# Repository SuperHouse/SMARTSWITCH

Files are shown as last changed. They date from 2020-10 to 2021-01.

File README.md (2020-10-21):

SuperHouse Home Automation SmartSwitch
=======================================

Home automation light switch that can be constructed with different
button panels, all using the same logic board. This allows the same
logic board and software to be used for either single-colour or RGB
button panels, in sizes from 1 to 4 buttons.

The switch can either operate in isolation using WiFi and local power,
or it can connect to a central light switch controller via Cat-5
cable.

It's designed to mount in a standard Australian blank wall plate,
but can also fit other types of wall plate.

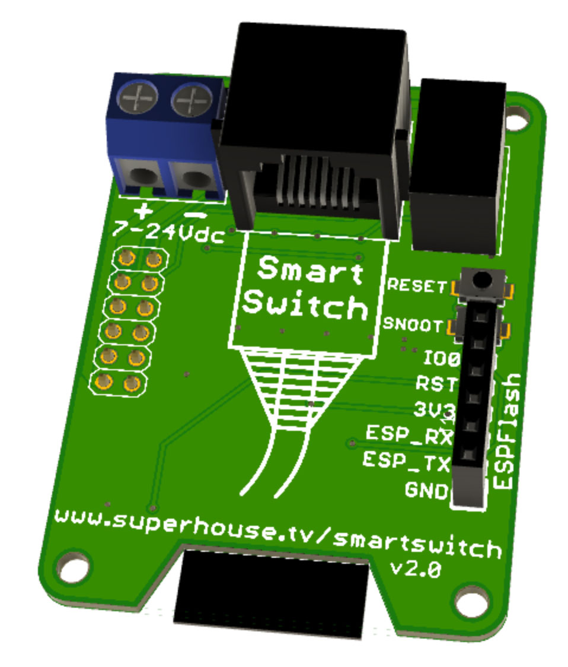
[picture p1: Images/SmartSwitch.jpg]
SmartSwitch


Features:

 * ESP8266 with WiFi
 * RJ45 socket to allow connecting using Cat-5 cable.
 * Either single-colour or RGB buttons.
 * From 1 to 4 buttons per panel.
 * WS2811 LED controllers.

More information is available at:

  https://www.superhouse.tv/smartswitch

Hardware
--------
The "Hardware" directory contains the PCB design as an EAGLE project.
EAGLE PCB design software is available from Autodesk free for
non-commercial use.

Credits
-------
 * Jonathan Oxer <jon@oxer.com.au>

License
-------
Copyright 2014-2020 SuperHouse Automation Pty Ltd  www.superhouse.tv  

The hardware portion of this project is licensed under the TAPR Open
Hardware License (www.tapr.org/OHL). The "license" folder within this
repository contains a copy of this license in plain text format.

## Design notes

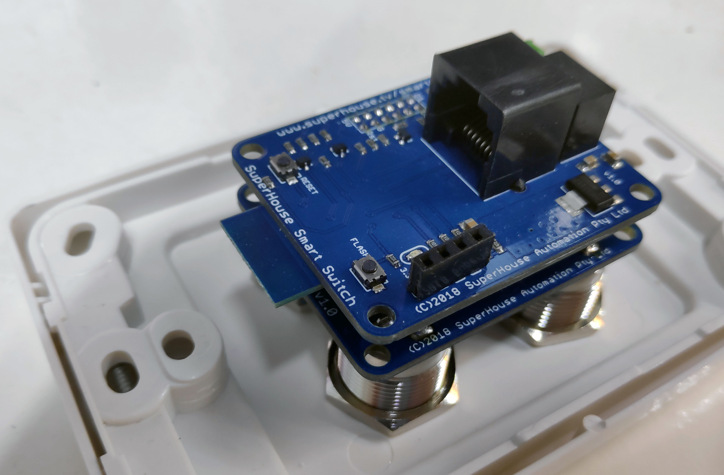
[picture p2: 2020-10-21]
Images/2019-02-13 13.19.25.jpg

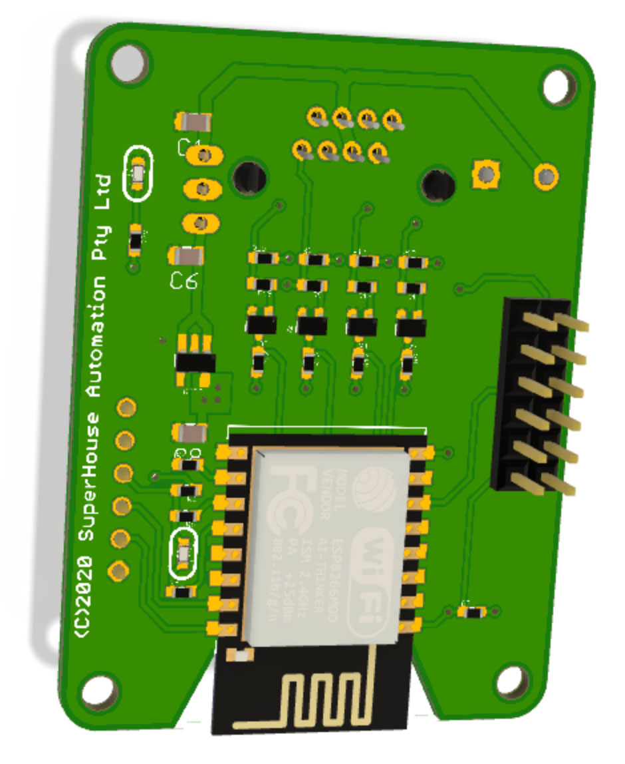
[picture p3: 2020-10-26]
Images/Screen Shot 2020-10-27 at 12.18.09 am.jpg

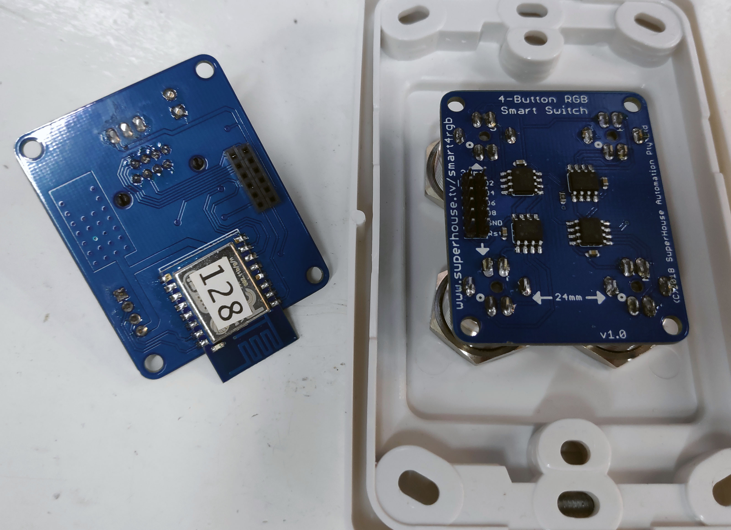
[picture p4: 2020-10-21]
Images/2019-02-13 13.19.00.jpg

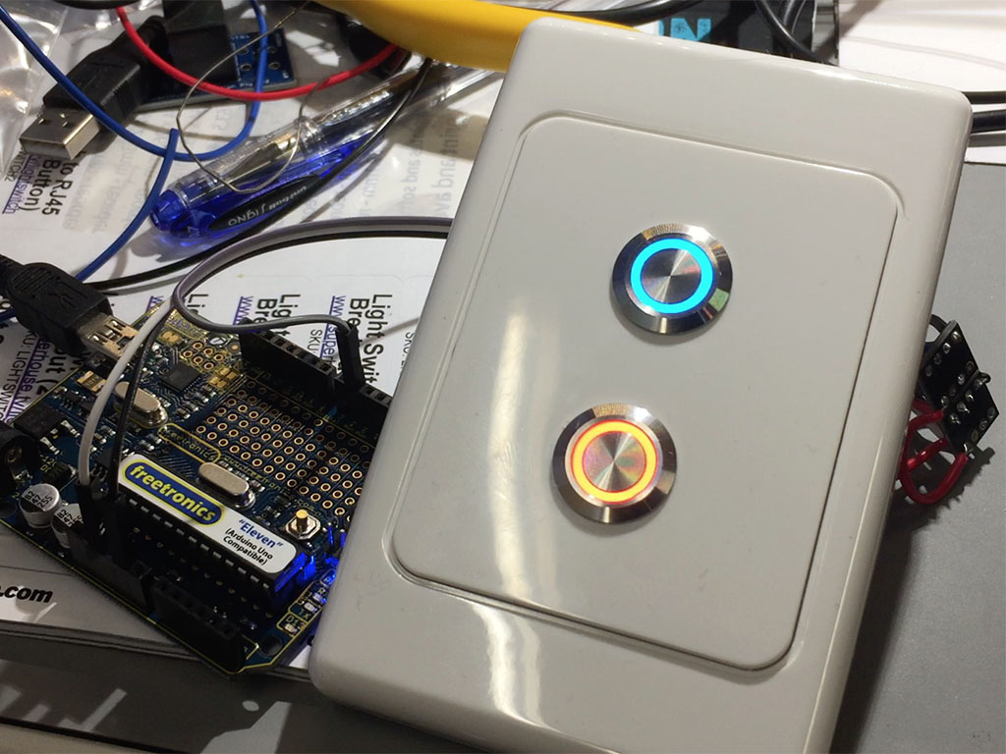
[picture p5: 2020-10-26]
Images/light-switch-prototype.jpg

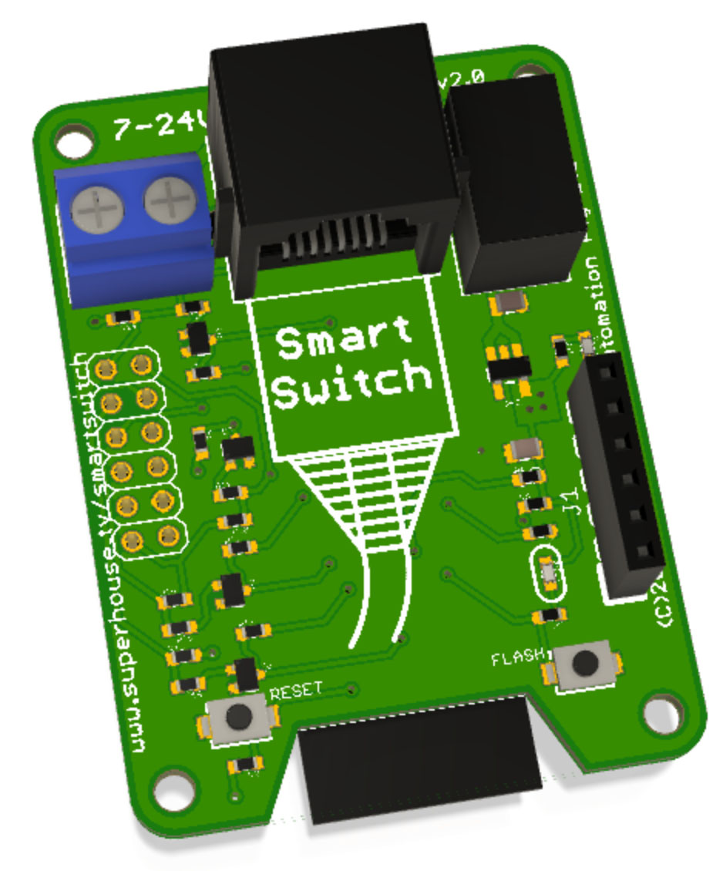
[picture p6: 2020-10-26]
Images/Screen Shot 2020-10-23 at 11.40.12 pm.jpg

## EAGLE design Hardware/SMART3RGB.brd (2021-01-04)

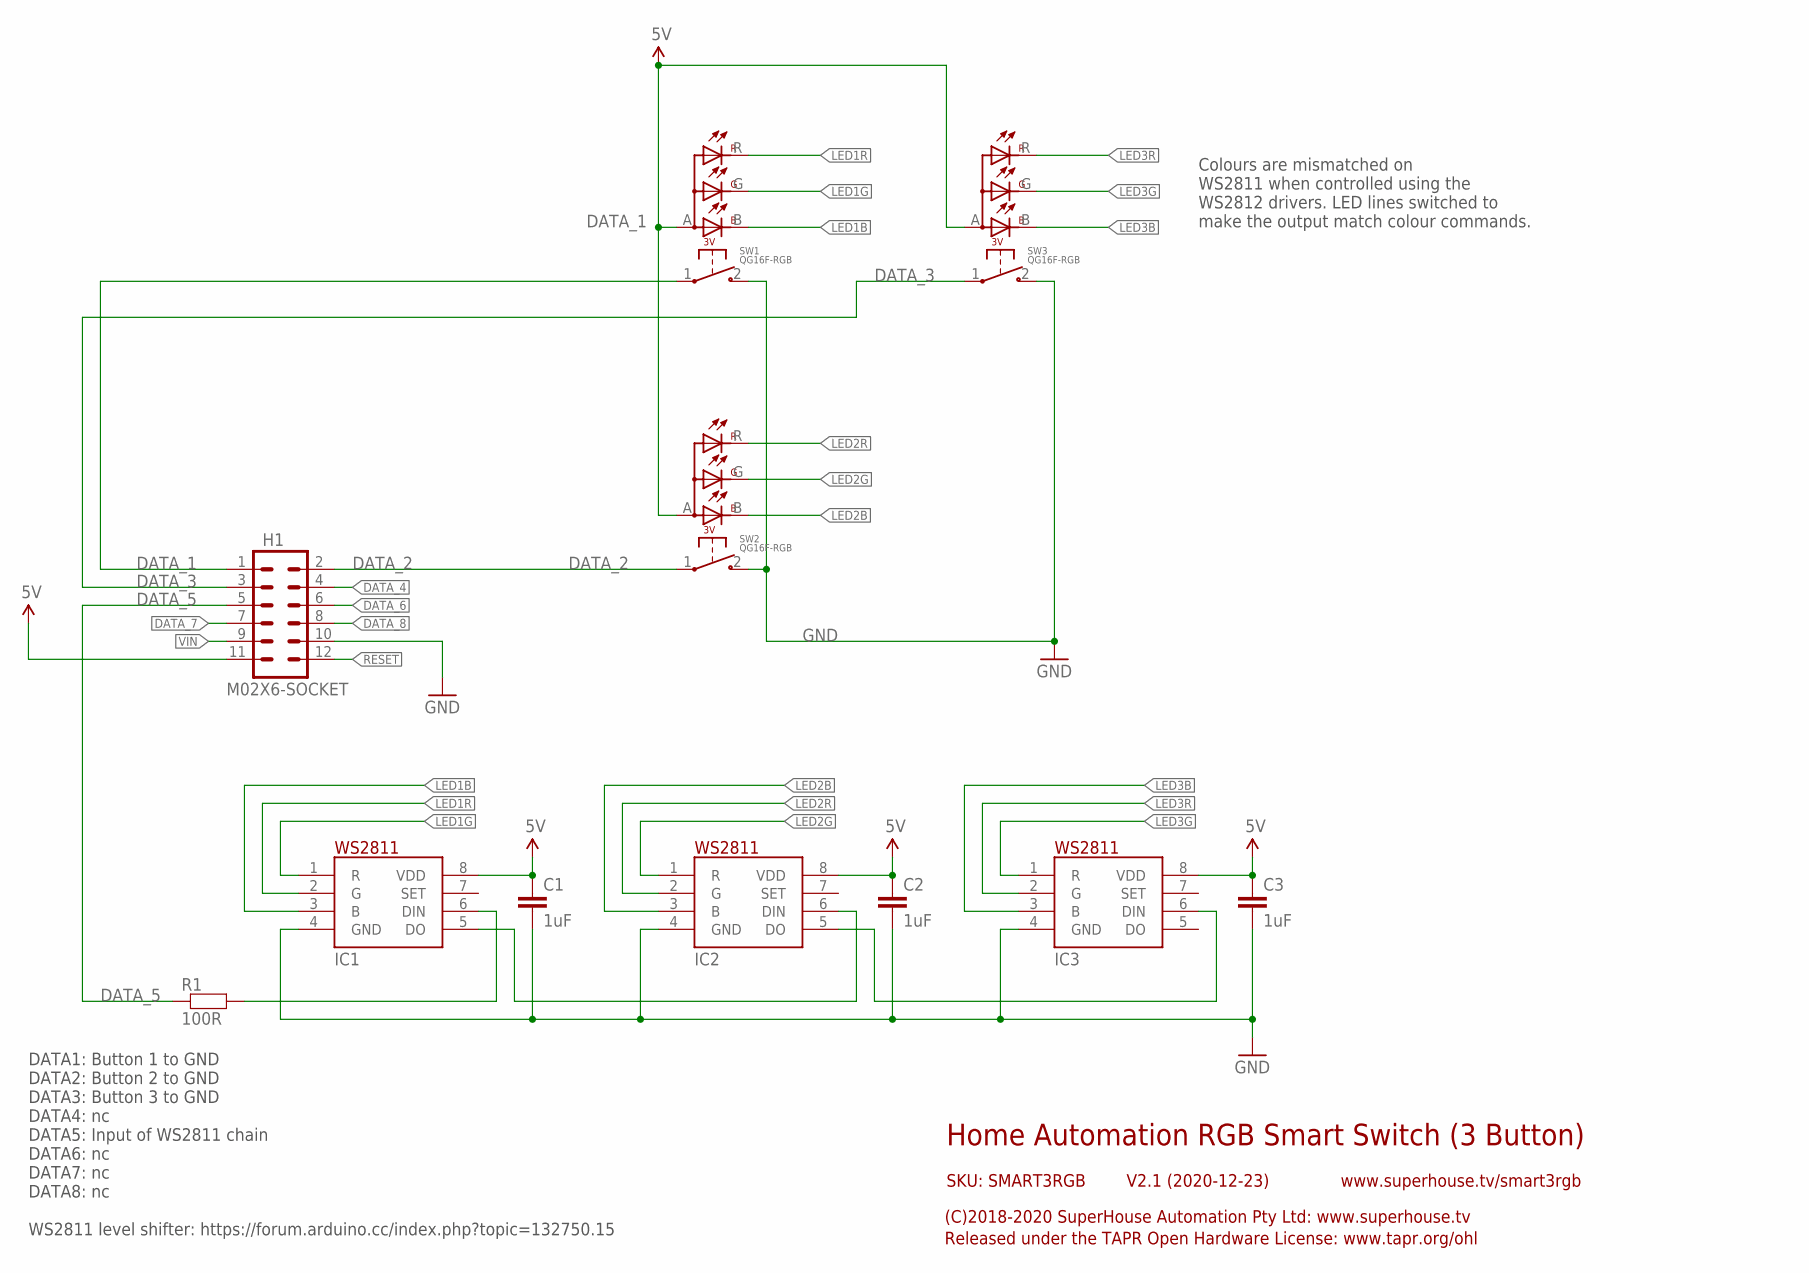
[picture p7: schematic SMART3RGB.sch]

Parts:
C1, C2, C3: 1uF; C0603
H1: M02X6-SOCKET; 2X06-S
IC1, IC2, IC3: WS2811-SOP8; SO08-SKINNYPADS
R1: 100R; R0603
SW1, SW2, SW3: QG16F-RGB

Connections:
5V: C1.1, C2.1, C3.1, H1.11, IC1.8 (VDD), IC2.8 (VDD), IC3.8 (VDD), SW1.A (+), SW2.A (+), SW3.A (+)
DATA_1: H1.1, SW1.1
DATA_2: H1.2, SW2.1
DATA_3: H1.3, SW3.1
DATA_4: H1.4
DATA_5: H1.5, R1.1
DATA_6: H1.6
DATA_7: H1.7
DATA_8: H1.8
GND: C1.2, C2.2, C3.2, H1.10, IC1.4 (GND), IC2.4 (GND), IC3.4 (GND), SW1.2, SW2.2, SW3.2
LED1B: IC1.3 (B), SW1.B
LED1G: IC1.1 (R), SW1.G
LED1R: IC1.2 (G), SW1.R
LED2B: IC2.3 (B), SW2.B
LED2G: IC2.1 (R), SW2.G
LED2R: IC2.2 (G), SW2.R
LED3B: IC3.3 (B), SW3.B
LED3G: IC3.1 (R), SW3.G
LED3R: IC3.2 (G), SW3.R
unnamed: IC1.6 (DIN), R1.2
unnamed: IC1.5 (DO), IC2.6 (DIN)
unnamed: IC2.5 (DO), IC3.6 (DIN)
RESET: H1.12
VIN: H1.9

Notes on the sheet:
Home Automation RGB Smart Switch (3 Button)
V2.1 (2020-12-23)
SKU: SMART3RGB
(C)2018-2020 SuperHouse Automation Pty Ltd: www.superhouse.tv
Released under the TAPR Open Hardware License: www.tapr.org/ohl
www.superhouse.tv/smart3rgb
DATA1: Button 1 to GND DATA2: Button 2 to GND DATA3: Button 3 to GND DATA4: nc DATA5: Input of WS2811 chain DATA6: nc DATA7: nc DATA8: nc WS2811 level shifter: https://forum.arduino.cc/index.php?topic=132750.15
Colours are mismatched on WS2811 when controlled using the WS2812 drivers. LED lines switched to make the output match colour commands.

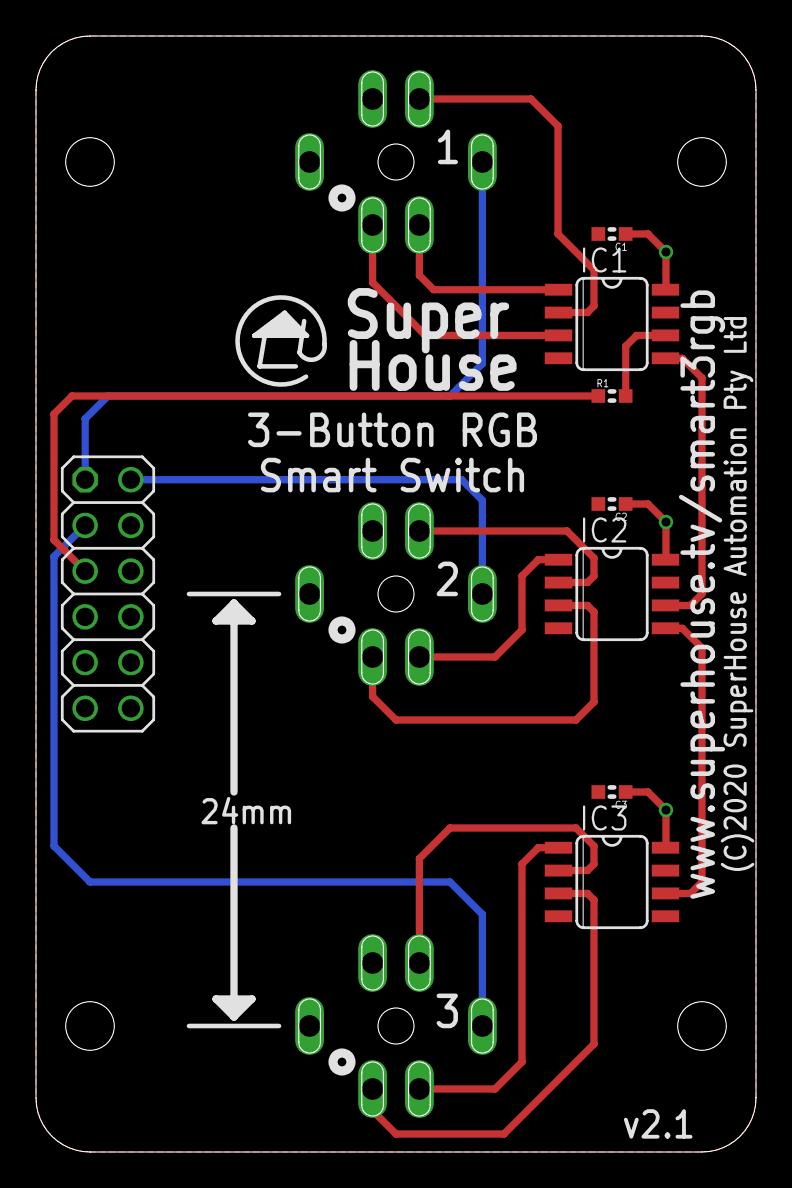
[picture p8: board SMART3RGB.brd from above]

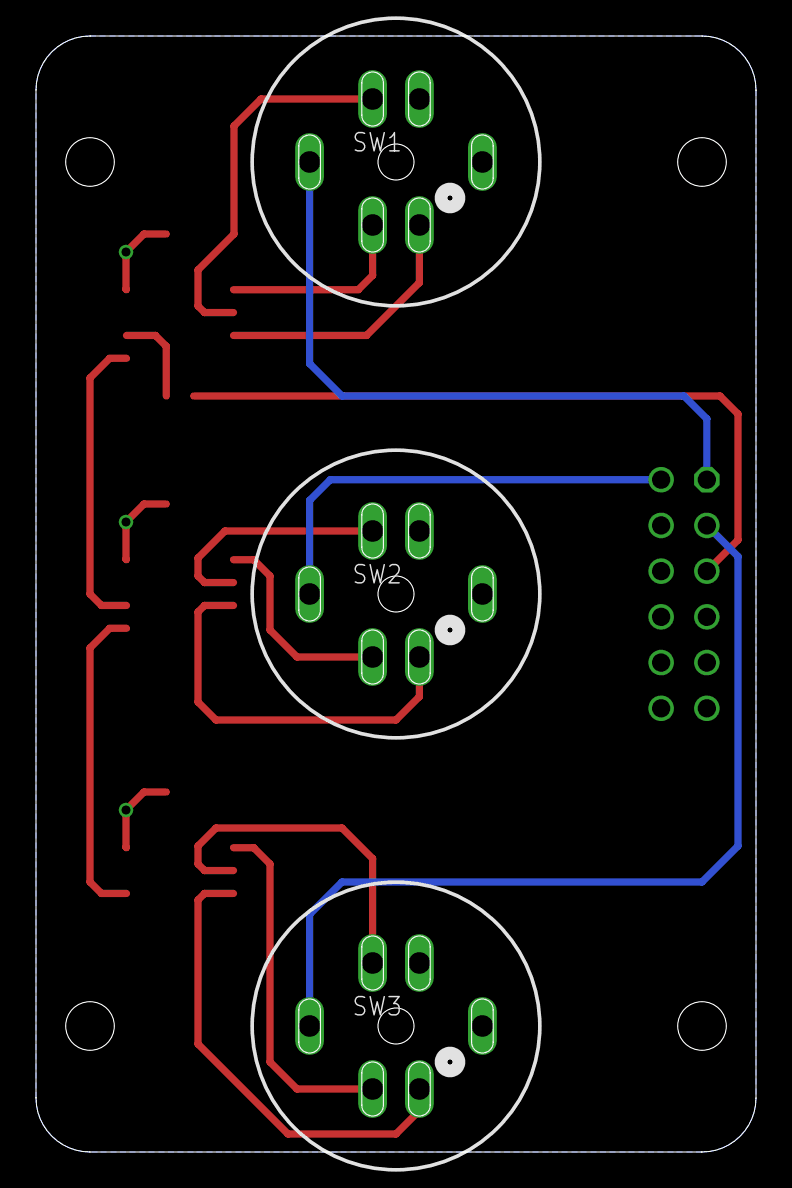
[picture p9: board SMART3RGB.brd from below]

Board: 2 copper layers, 40.0 x 62.0 mm, 11 parts (3 on the bottom side), 18 nets.

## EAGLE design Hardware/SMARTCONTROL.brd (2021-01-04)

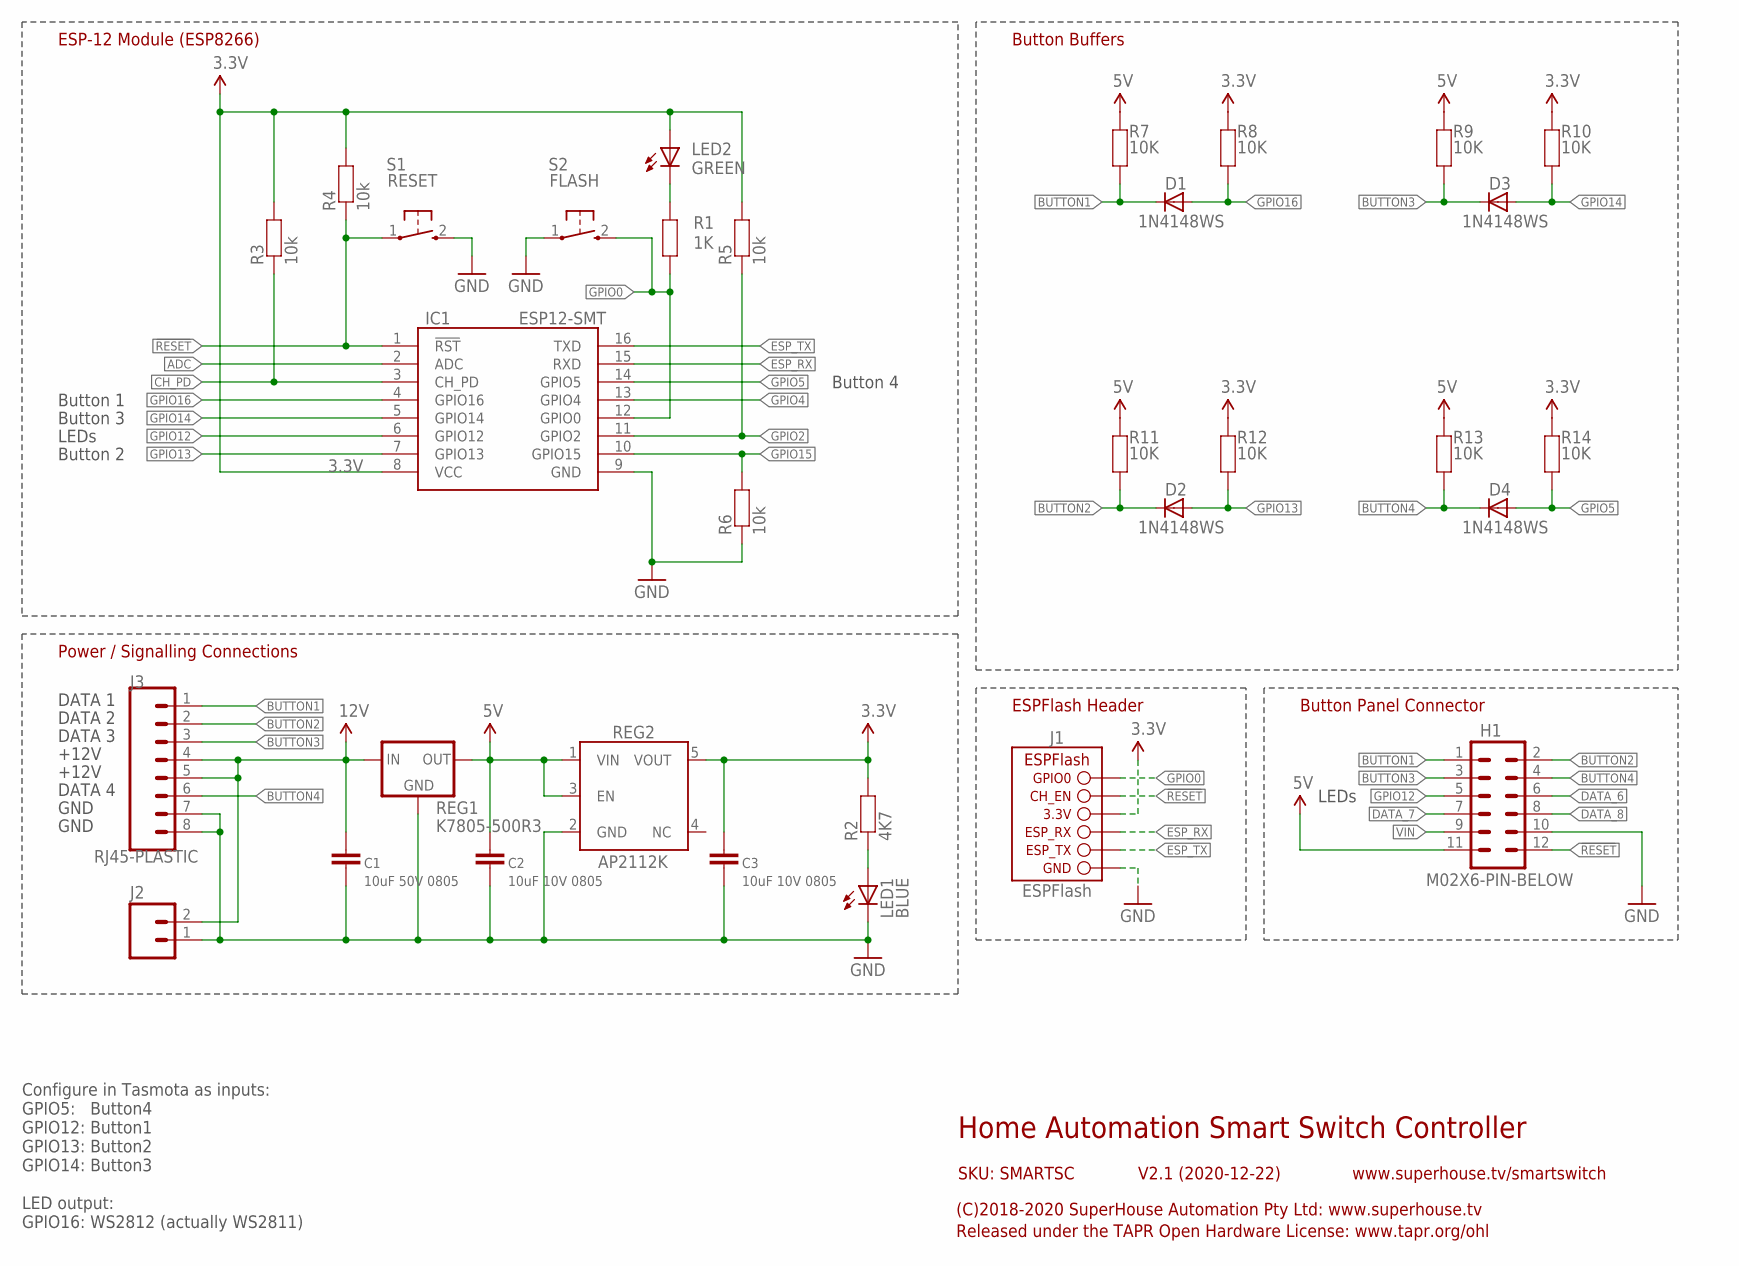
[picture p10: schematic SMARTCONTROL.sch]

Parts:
C1: 10uF 50V 0805; C0805
C2, C3: 10uF 10V 0805; C0805
D1, D2, D3, D4: 1N4148WS; SOD-323
H1: M02X6-PIN-BELOW; 2X06-P-BELOW
IC1: ESP12-SMT; ESP12
J1: ESPFLASH-1X6-2.54-SOCKET; 1X6-2.54-SOCKET
J2: M02-SCREW-5MM; SCREWTERMINAL-5MM-2
J3: RJ45-PLASTIC; RJ45
LED1: BLUE; LED-0603
LED2: GREEN; LED-0603
R1: 1K; R0603
R2: 4K7; R0603
R3, R4, R5, R6: 10k; R0603
R7, R8, R9, R10, R11, R12, R13, R14: 10K; R0603
REG1: K7805-500R3; K78XX-500R3
REG2: AP2112KSOT25; SOT23-5
S1: RESET; TACTILE_SMT_3X4X2
S2: FLASH; TACTILE_SMT_3X4X2

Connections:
3.3V: C3.1, IC1.8 (VCC), J1.4 (3.3V), LED2.A, R2.2, R3.2, R4.2, R5.2, R8.2, R10.2, R12.2, R14.2, REG2.5 (VOUT)
5V: C2.1, H1.11, R7.2, R9.2, R11.2, R13.2, REG1.3 (OUT), REG2.1 (VIN), REG2.3 (EN)
12V: C1.1, J2.2, J3.4, J3.5, REG1.1 (IN)
!RESET: H1.12, IC1.1 (!RST), J1.5 (CH_EN), R4.1, S1.1
ADC: IC1.2 (ADC)
BUTTON1: D1.1 (C), H1.1, J3.1, R7.1
BUTTON2: D2.1 (C), H1.2, J3.2, R11.1
BUTTON3: D3.1 (C), H1.3, J3.3, R9.1
BUTTON4: D4.1 (C), H1.4, J3.6, R13.1
CH_PD: IC1.3 (CH_PD), R3.1
DATA_6: H1.6
DATA_7: H1.7
DATA_8: H1.8
ESP_RX: IC1.15 (RXD), J1.3 (ESP_RX)
ESP_TX: IC1.16 (TXD), J1.2 (ESP_TX)
GND: C1.2, C2.2, C3.2, H1.10, IC1.9 (GND), J1.1 (GND), J2.1, J3.7, J3.8, LED1.C, R6.1, REG1.2 (GND), REG2.2 (GND), S1.2 (S), S2.1
GPIO0: IC1.12 (GPIO0), J1.6 (GPIO0), R1.2, S2.2 (S)
GPIO2: IC1.11 (GPIO2), R5.1
GPIO4: IC1.13 (GPIO4)
GPIO5: D4.2 (A), IC1.14 (GPIO5), R14.1
GPIO12: H1.5, IC1.6 (GPIO12)
GPIO13: D2.2 (A), IC1.7 (GPIO13), R12.1
GPIO14: D3.2 (A), IC1.5 (GPIO14), R10.1
GPIO15: IC1.10 (GPIO15), R6.2
GPIO16: D1.2 (A), IC1.4 (GPIO16), R8.1
unnamed: LED1.A, R2.1
unnamed: LED2.C, R1.1
VIN: H1.9

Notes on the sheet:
Home Automation Smart Switch Controller
V2.1 (2020-12-22)
SKU: SMARTSC
(C)2018-2020 SuperHouse Automation Pty Ltd: www.superhouse.tv
Released under the TAPR Open Hardware License: www.tapr.org/ohl
www.superhouse.tv/smartswitch
Configure in Tasmota as inputs: GPIO5: Button4 GPIO12: Button1 GPIO13: Button2 GPIO14: Button3 LED output: GPIO16: WS2812 (actually WS2811)
DATA 1
DATA 2
DATA 3
DATA 4
+12V
GND
Button 1
Button 2
Button 3
Button 4
LEDs
Button Panel Connector
ESP-12 Module (ESP8266)
Button Buffers
Power / Signalling Connections
ESPFlash Header

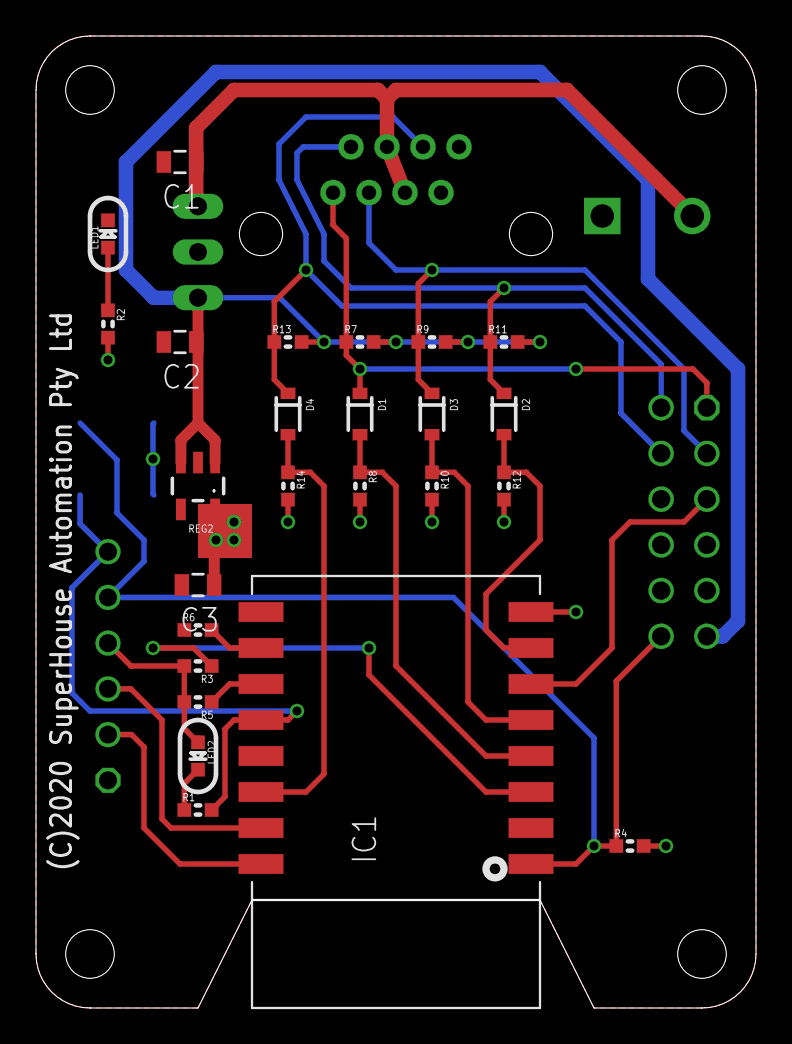
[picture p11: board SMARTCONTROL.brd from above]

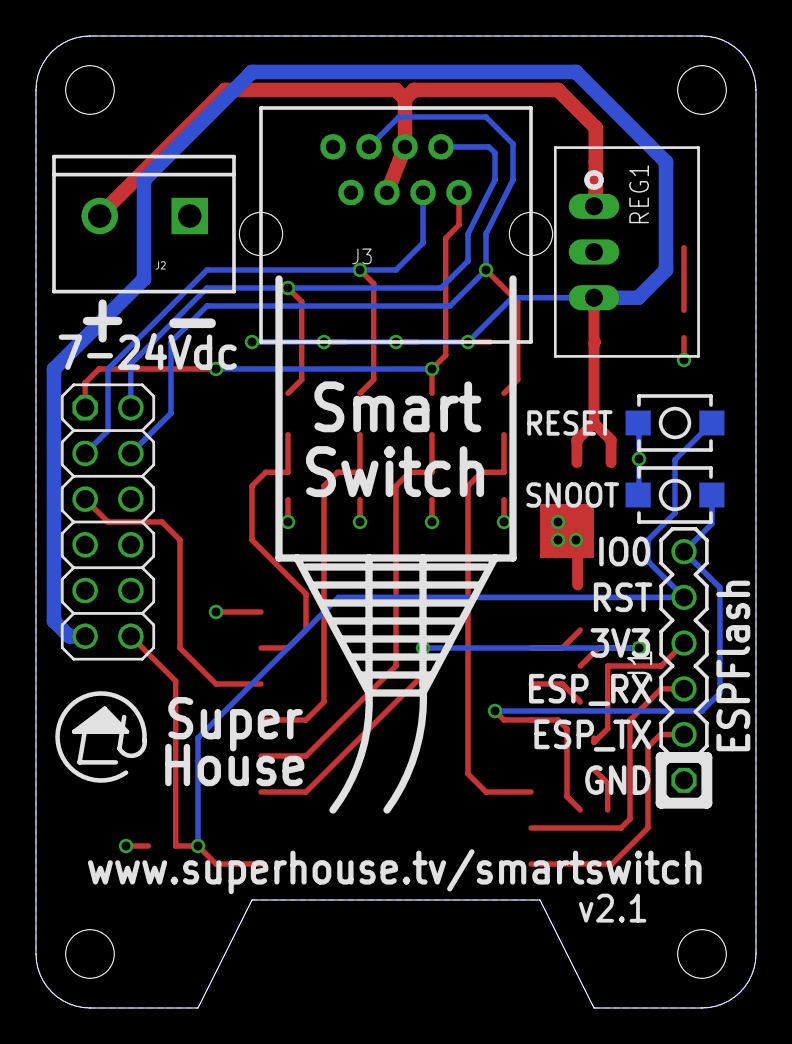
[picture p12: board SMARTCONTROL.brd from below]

Board: 2 copper layers, 40.0 x 54.0 mm, 32 parts (7 on the bottom side), 22 nets.

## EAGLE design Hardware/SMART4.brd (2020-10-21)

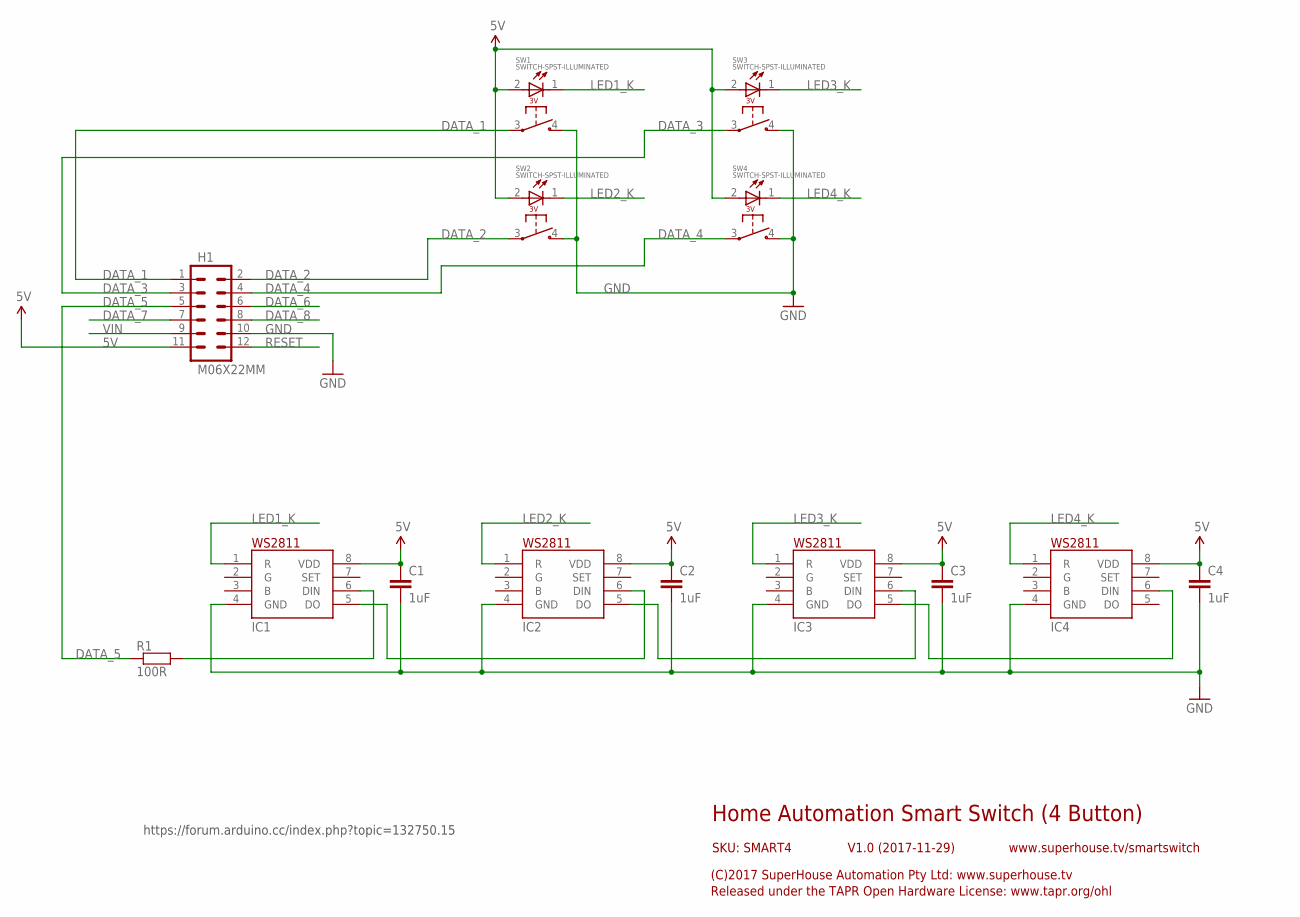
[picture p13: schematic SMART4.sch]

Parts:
C1, C2, C3, C4: 1uF; 0603
H1: M06X22MM; 2X6-2MM
IC1, IC2, IC3, IC4: WS2811-SOP8; SO08-SKINNYPADS
R1: 100R; 0603
SW1, SW2, SW3, SW4: SWITCH-SPST-ILLUMINATED

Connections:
5V: C1.1, C2.1, C3.1, C4.1, H1.11, IC1.8 (VDD), IC2.8 (VDD), IC3.8 (VDD), IC4.8 (VDD), SW1.2 (+), SW2.2 (+), SW3.2 (+), SW4.2 (+)
DATA_1: H1.1, SW1.3 (COM)
DATA_2: H1.2, SW2.3 (COM)
DATA_3: H1.3, SW3.3 (COM)
DATA_4: H1.4, SW4.3 (COM)
DATA_5: H1.5, R1.1
DATA_6: H1.6
DATA_7: H1.7
DATA_8: H1.8
GND: C1.2, C2.2, C3.2, C4.2, H1.10, IC1.4 (GND), IC2.4 (GND), IC3.4 (GND), IC4.4 (GND), SW1.4 (NO), SW2.4 (NO), SW3.4 (NO), SW4.4 (NO)
LED1_K: IC1.1 (R), SW1.1 (-)
LED2_K: IC2.1 (R), SW2.1 (-)
LED3_K: IC3.1 (R), SW3.1 (-)
LED4_K: IC4.1 (R), SW4.1 (-)
unnamed: IC1.6 (DIN), R1.2
unnamed: IC1.5 (DO), IC2.6 (DIN)
unnamed: IC2.5 (DO), IC3.6 (DIN)
unnamed: IC3.5 (DO), IC4.6 (DIN)
RESET: H1.12
VIN: H1.9

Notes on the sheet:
Home Automation Smart Switch (4 Button)
V1.0 (2017-11-29)
SKU: SMART4
(C)2017 SuperHouse Automation Pty Ltd: www.superhouse.tv
Released under the TAPR Open Hardware License: www.tapr.org/ohl
www.superhouse.tv/smartswitch
https://forum.arduino.cc/index.php?topic=132750.15

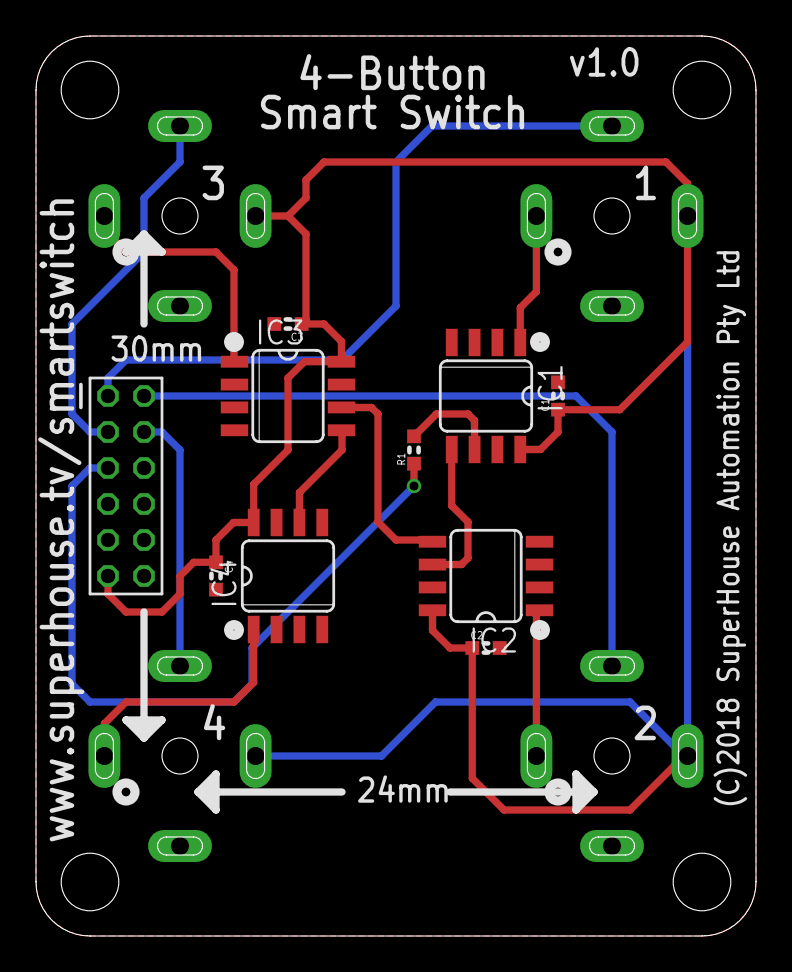
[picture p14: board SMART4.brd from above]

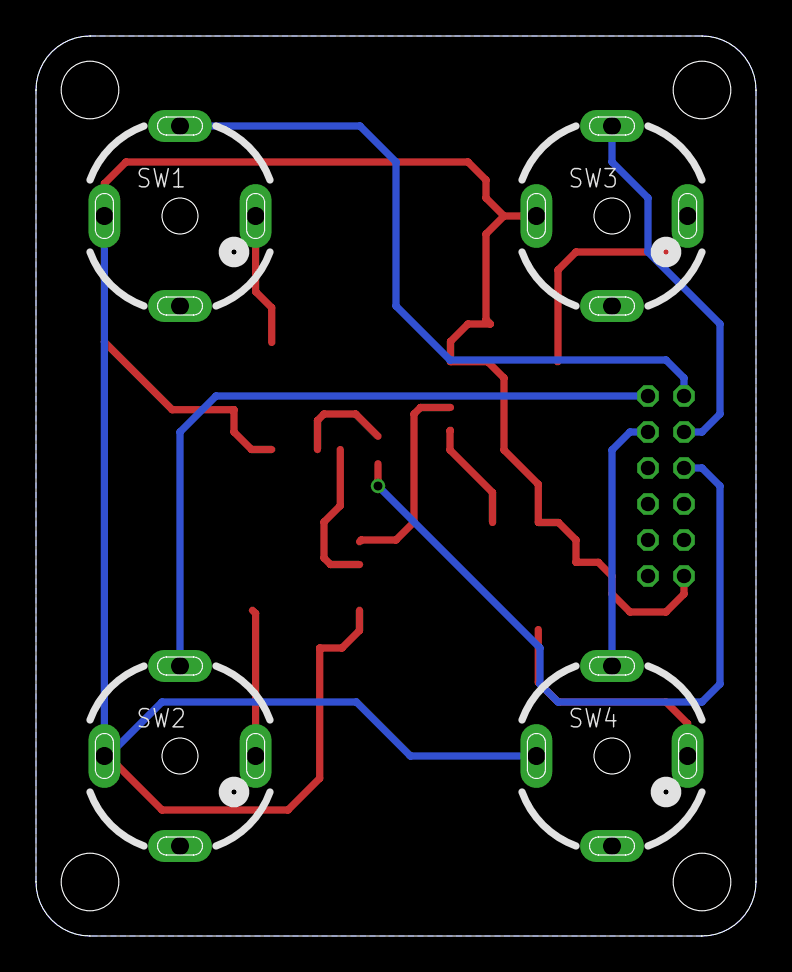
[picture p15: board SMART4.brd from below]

Board: 2 copper layers, 40.0 x 50.0 mm, 14 parts (4 on the bottom side), 15 nets.

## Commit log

2020-10-21 Merged separate projects into one common SmartSwitch project
    [SMART4.brd, SMART4.sch, SMART4RGB.brd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]
2020-10-21 Replaced 3.3V regulator. Switched button1 and LED pins. Extended PCB to improve bolt clearance. Changed bottom layer to 3.3V.
    [SMARTCONTROL.brd, SMARTCONTROL.sch]
2020-10-25 Routing for expanded PCB.
    [SMARTCONTROL.brd, SMARTCONTROL.sch]
2020-10-26 Created alternative version of board with parts underneath.
    [SMARTCONTROL2.brd, SMARTCONTROL2.sch]
2020-11-06 Moved v2 board back to original name, and finished ERC/DRC for v2.0 release.
    [SMARTCONTROL.brd, SMARTCONTROL2.brd, SMARTCONTROL2.sch]
2020-11-06 Alter size of board and hole locations to match updated controller. Switch green and blue connections to make colours match WS2812 profile.
    [SMART4RGB.brd, SMART4RGB.sch]
2020-11-06 Update F360 link.
    [SMARTCONTROL.brd]
2020-11-06 Forked 4-button version to make 3-button version.
    [SMART3RGB.brd, SMART3RGB.sch]
2020-11-07 Routing, ERC, and DRC for v2.0 release.
    [SMART3RGB.brd, SMART3RGB.sch]
2020-11-07 Duplicated project files for 2-button version.
    [SMART2RGB.brd, SMART2RGB.sch]
2020-11-07 Final routing, ERC, and DRC for v2.0 release.
    [SMART2RGB.brd, SMART2RGB.sch]
2021-01-04 Converted switch isolation from FETs to diodes for v2.1 release.
    [SMART2RGB.brd, SMART2RGB.sch, SMART3RGB.brd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]

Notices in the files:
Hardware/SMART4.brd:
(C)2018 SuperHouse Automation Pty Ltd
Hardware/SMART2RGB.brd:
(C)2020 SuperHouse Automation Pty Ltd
